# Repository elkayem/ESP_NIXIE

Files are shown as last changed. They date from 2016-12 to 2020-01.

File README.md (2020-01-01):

# ESP_NIXIE

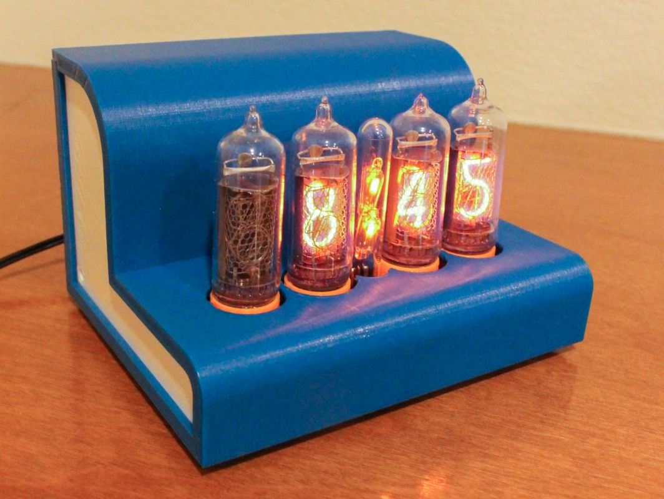
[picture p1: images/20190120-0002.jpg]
Clock 

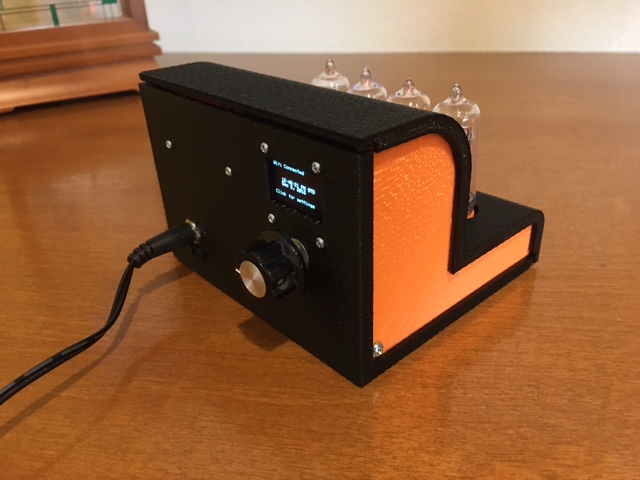
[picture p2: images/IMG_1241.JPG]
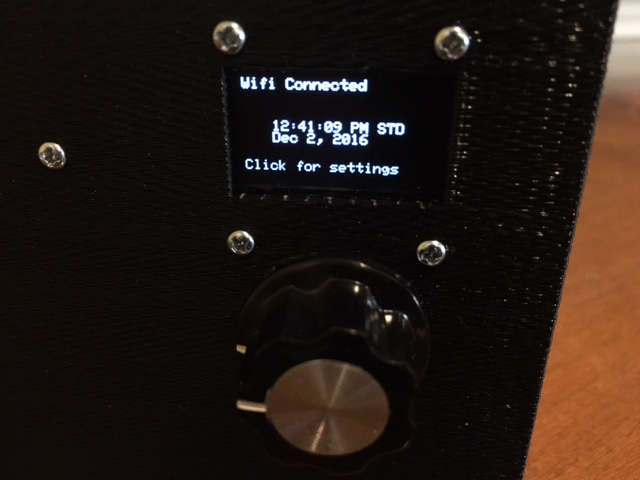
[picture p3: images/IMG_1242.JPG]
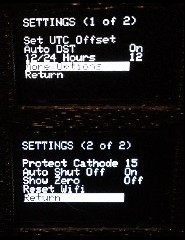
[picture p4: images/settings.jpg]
  

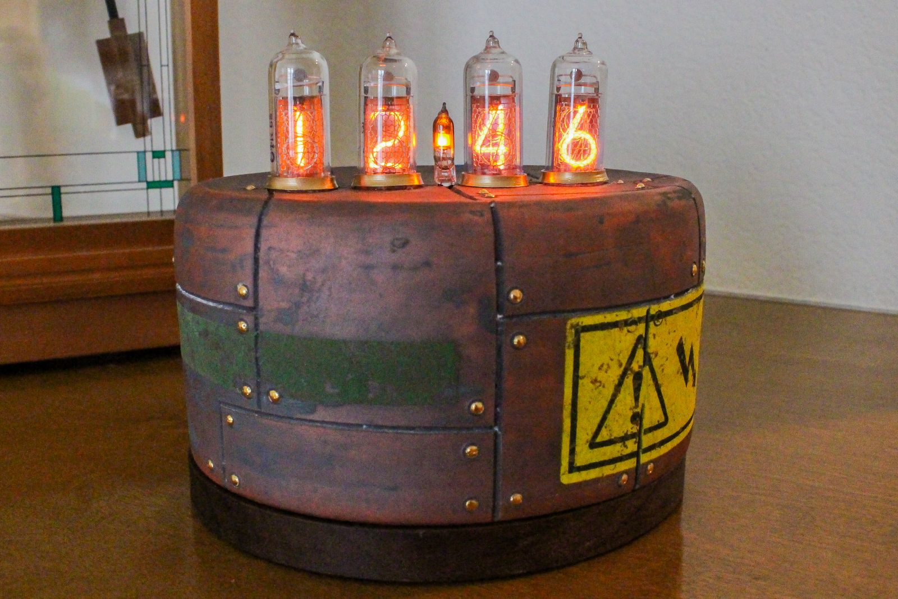
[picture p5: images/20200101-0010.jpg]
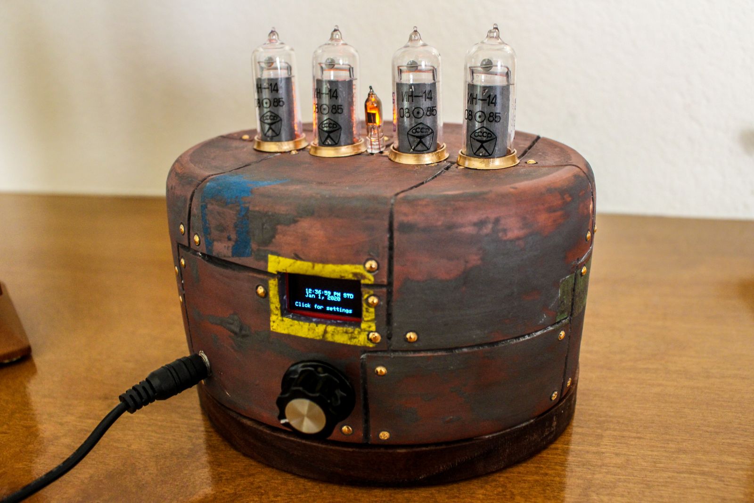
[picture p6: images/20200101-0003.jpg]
  

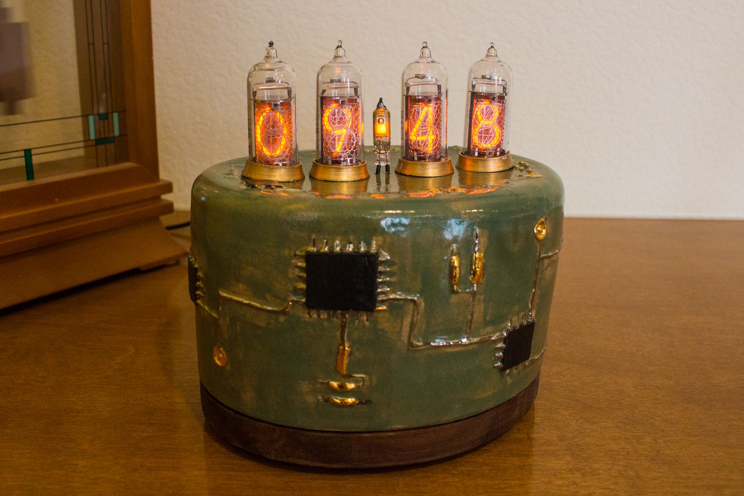
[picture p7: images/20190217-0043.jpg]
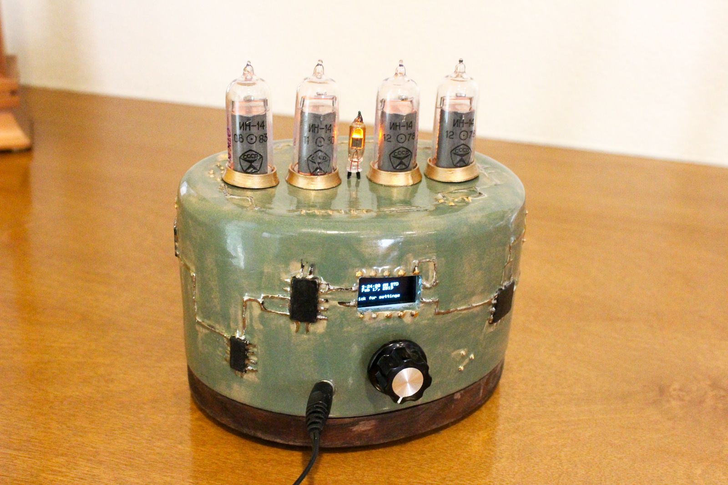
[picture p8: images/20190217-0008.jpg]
  

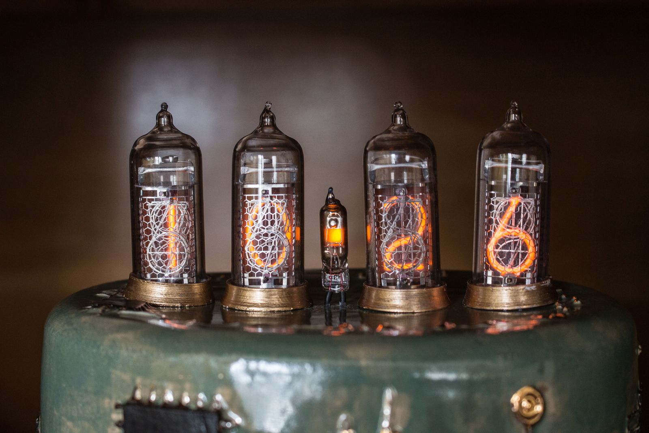
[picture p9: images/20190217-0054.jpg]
 

Building a Nixie Clock is a time honored tradition among makers, and this is yet another DIY Nixie Clock project.  This one is unique in a few respects: 1) it uses an ESP8266 development board as the microcontroller, allowing it to automatically sync its time to NIST over WiFi, and 2) it features a 3D printed frame and hand-solderable PCB. 

These electronics have also been incorporated into a ceramic case by the talented artist [Jackson Fyfe](https://www.jacksonfyfeceramics.com/).  The case you see pictured above is one he created for me.  Head over to his website to see a number of his other stunning Nixie case designs, which he is selling as a limited release.

This repository contains the code, and schematics for driving a Nixie tube clock with a NodeMCU 1.0 ESP8266 development board.  STL files are also provided for a 3D printed case.  Two variants of the PCB and 3D printed cases are available, a PCB and case without a colon separator circuit, and a PCB and case with a colon separator circuit.  The code is the same, with a single #define statement that can be commented to compile the option without the separator circuit.   

When the clock is turned on for the first time, it will create a WiFi access point at ESPNIXIE that can be connected to using a computer or smartphone.  The user can use this access point to specify the WiFi network SSID and password.  This information is stored in EEPROM, so will not be needed the next time the clock is turned on.  It uses the Arduino [Wifi Manager](https://github.com/tzapu/WiFiManager) to create the access point.  

This clock includes a menu-driven OLED screen and rotary encoder, with menu options described below.  All settings are stored in EEPROM so they can be used after a power cycle.
* *Set UTC Offset.*  The user's local time zone is selected by adjusting the time offset from UTC time.
* *Auto DST.* This option enables/disables automatic daylight savings time.  The code includes rules for US Daylight Savings Time (second Sunday in March at 2am to first Sunday in November at 2am).  The code can easily be modified for rules in other countries.
* *12/24 Hours.* This option selects between 12 and 24 hour time formats.
* *Blink Colon.* This option is available if using a colon separator.  If enabled, it will blink the colon once per second, otherwise it will keep the colon on steady.  This option is not available if #define CLOCK_COLON is commented in the code.  
* *Protect Cathode.* Nixie tubes are susceptible to cathode poisoning when material from an active cathode sputters on the inactive cathodes.  This process can be reversed by occasionally cycling through all numbers for short durations.  When enabled, this feature will cycle through all the numbers at a 10 Hz rate for 5 seconds.  Besides protecting the cathodes, it also looks cool.  Time intervals ranging from 15 minutes to two hours can be selected.
* *Auto Shutoff.* When enabled, this feature will automatically turn off the tubes between designated hours (e.g., during the night), helping to preserve Nixie tube life.  The off and on times are selectable through a submenu.
* *Screensaver.* When enabled, a screensaver will activate on the OLED if the menu has been inactive for more than 60 seconds.  OLEDs are subject to screen burn-in, and this will help alleviate that issue.  Two screensaver options are available.  The first displays a scrolling image, and the second simply turns the OLED display off.
* *Show Zero.* This option allows the user to select whether the left most Nixie tube (tens place for the hour) should be turned off when it is zero, or whether zero should be shown.  
* *Reset Wifi.*  Selecting this will cause the ESP8266 to forget the current WiFi network.  The clock will reboot and set up a new WiFi access point at ESPNIXIE.   

In addition to these settings, holding the rotary encoder button down for more than three seconds will manually toggle the Nixie tubes on and off.  If the Auto Shutoff feature is enabled, the Nixies will stay on or off as selected until the next Auto Shutoff transition occurs, after which the Nixie tubes will turn on and off according to the Auto Shutoff schedule.

**Please PM me if you would like a set of printed circuit boards.** I have enough extras to make a few more ESP Nixie clocks.  

## Parts
* NodeMCU V1.0 (Amica board).  Clone boards often are unofficially labeled as V2
* 4 IN-14 Nixie Tubes
* 1 0.96" I2C 128x64 OLED display
* 1 Rotary Encoder
* 1 12VDC 1A Wall Adapter Power Supply
* 1 NCH6100HV High Voltage DC Power Supply (or equivalent)
* 1 Nixie Board PCB (options with or without colon separator circuit).  I've included the Eagle schematic, board layout, and gerber files in this repository for both options.  
* 2 15-pin female headers
* Lots of male breakaway headers (I haven't counted, buy a pack)
* 6 16-pin DIP IC Sockets
* 4 Nixie Tube PCBs.  Files included in this repository.  This can also easily be created using a strip board.
* 2 74HC595N shift registers
* 4 74141N BCD to Decimal Decoders (or K155ID1 Russian equivalents)
* 1 L7805 5V regulator (an additional heat sink is recommended)
* 1 0.33 uF capacitor
* 1 0.1 uF capacitor
* 1 3 Pin 5.08mm Pitch PCB Mount Screw Terminal  
* 1 2 Pin 5.08mm Pitch PCB Mount Screw Terminal 
* 4 15K Ohm resistors
* 1 20K Ohm resistor (used to illuminate decimal point if not using colon separator circuit.  However, I no longer recommend using this resistor for ascetic reasons.)
* Various M2 and M3 bolts
* 8 female-female short jumper cables.
* 1 MPSA42 Transistor (if using colon separator PCB)
* 2 200K Ohm resistors (if using colon separator circuit)
* 1 33K Ohm resistor (if using colon separator circuit)
* 1 IN-3 tube or 2 NE-2H tubes (if using colon separator circuit)

## Instructions
Most of these parts can be found on eBay or your favorite online Chinese retailer.  Although no longer manufactured, nixie tubes are still readily available, with the IN-14 selling for about $5-$10 per tube.  I recommend the NCH6100HV power supply, though there are many others out there capable of driving Nixie tubes.  The output voltage should be set to 170 V, which can be adjusted using an onboard potentiometer.  If selecting a different power supply, make sure it is capable of delivering at least 15 mA of continuous current at 170 V.

The Nixie Board PCB and tube PCBs must be manufactured by a PCB supplier.  The least expensive way to do this is to upload the gerber files (included as a .zip file) to one of several Chinese manufacturers such as JLCPCB, SchenZhen2U, or Seeed Studio.  pcbshopper.com allows a comparison between vendors.  Typical prices are $1-$3/board, with a minimum of 5 boards.  Recommended default settings are Layers: 2; PCB Thickness: 1.6mm; Surface Finish: HASL; Copper Weight: 1.  The main board is 100 x 80 mm, and the smaller tube boards are 20.7mm x 28.3mm.  

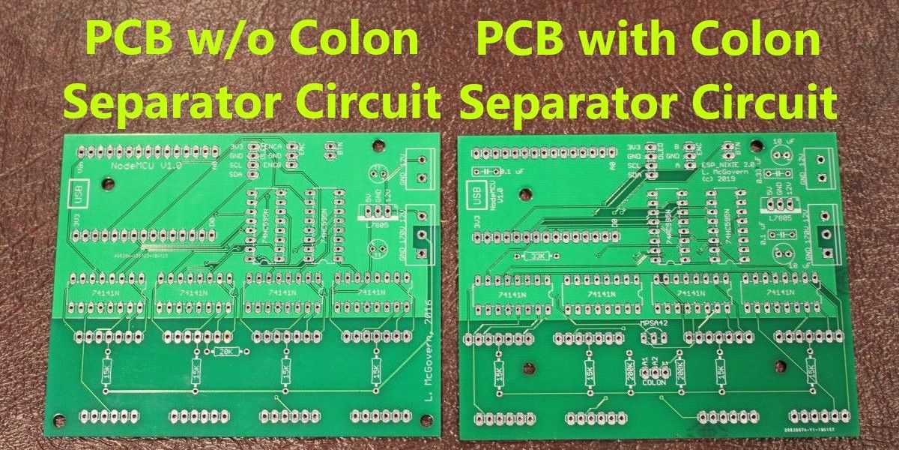
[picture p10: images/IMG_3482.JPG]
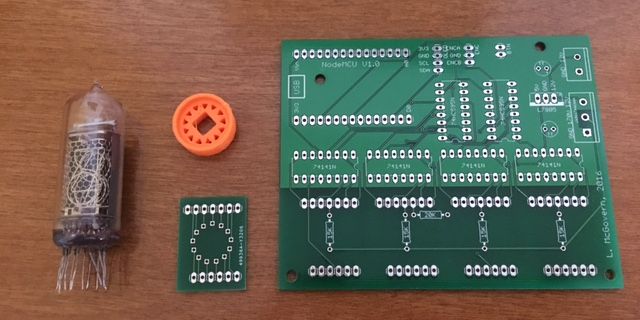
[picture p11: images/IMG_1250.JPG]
 

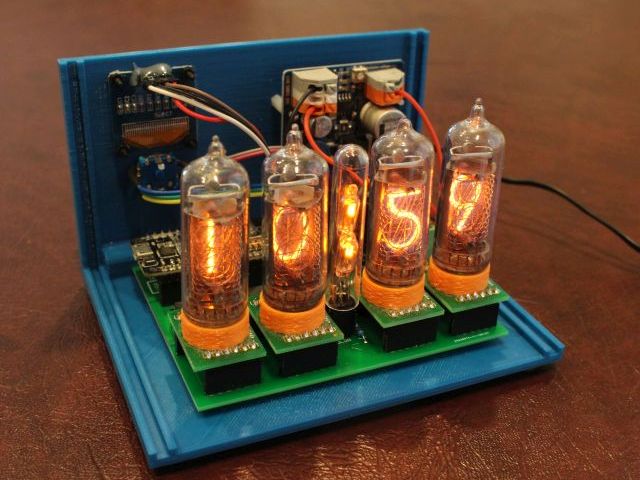
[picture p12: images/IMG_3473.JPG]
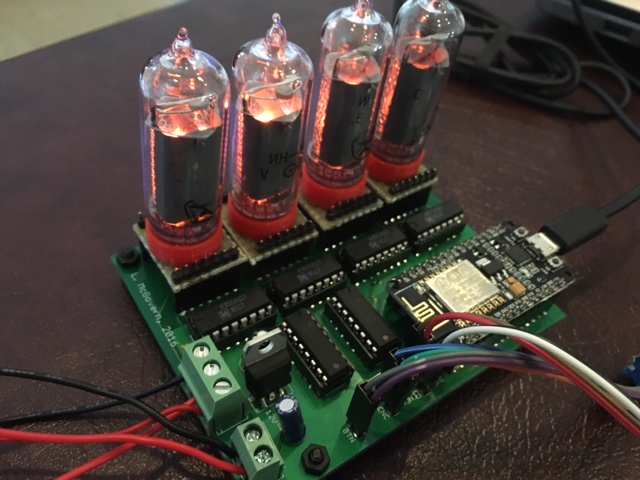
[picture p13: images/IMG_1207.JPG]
 

Solder headers, IC sockets, terminal blocks, resistors, voltage regulator, and capacitors to the board.  The 0.33 uF capacitor goes closest to the 2-pin terminal block.  The 20K Ohm resistor is marked as optional.  This will illuminate the decimal point between the hours and minutes.  Personally, I think it looks better without it and I did not use it, but it is there if others wish to use it.  Mount ICs, and NodeMCU to the headers and sockets.  

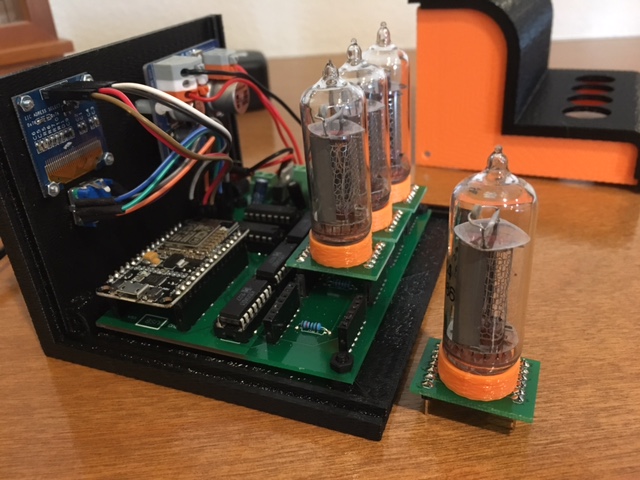
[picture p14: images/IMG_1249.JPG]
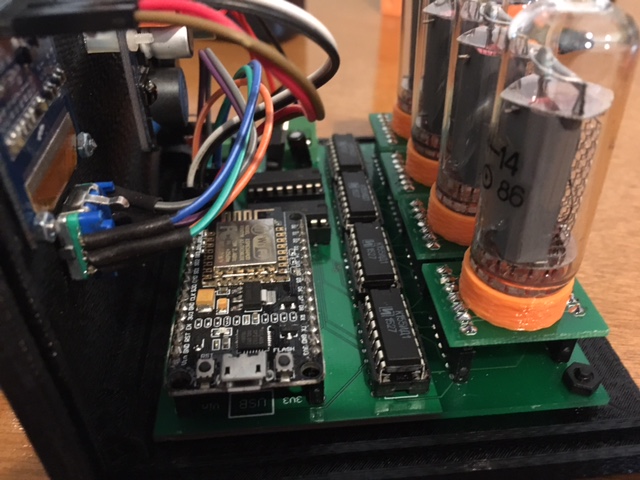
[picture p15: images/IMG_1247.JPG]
 

### Board Modifications
A few recommended modifications to the board are listed below. These changes will be incorporated into a future release of the board design. See figure below for suggested modifications to back of board.

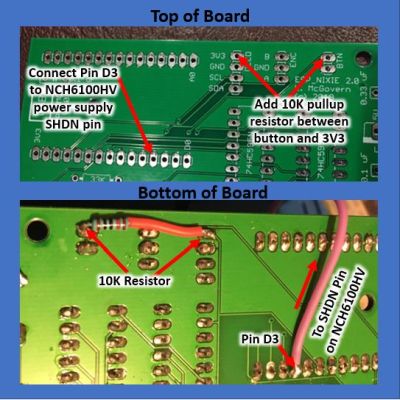
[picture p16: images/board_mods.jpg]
 

**Button Pullup Resistor.** The encoder button is attached to pin D0 (GPIO16). This button requires a 10K pullup resistor to keep D0 high when the button is not depressed.  Unfortunately, the ESP-12E module on the NodeMCU board does not have a pullup resistor on this pin. It does have an LED which can sometimes function as a pullup resistor, so it is possible that your NodeMCU board will work just fine without this modification. NodeMCU boards with a blue LED on pin D0 require the additional 10K pullup resistor, while boards with a red LED can often function without one. See above figure for suggested configuration, with the non-grounded side of the button pin connected to 3.3V via a 10K resistor. The resistor can be soldered to the back of the board.

**Power Supply Shutdown Pin (Optional).** The auto shutoff feature will turn off the Nixie tubes at night to preserve Nixie tube life. This is primarily done by controlling the 74141N transistors. This still leaves the Nixie anodes connected to the 170V power supply, which can show a slight orange glow on the tubes visible in the dark. If using the NCH6100HV power supply, the 170V output can be completely turned off using the SHDN pin on the power supply, thereby completely eliminating the orange glow. To take advantage of this feature, solder a wire on the back side of the ESP_NIXIE board to the D3 pin, and connect the other end of the wire to the SHDN pin on the NCH6100HV. See purple wire on the above photo for pin location on the board. 

### Final Assembly
3D print the parts.  The top cover is printed on its side, and will need supports to prevent the tube holes from sagging.  Four tube sockets are required.  

Mount Nixie tubes through 3D printed tube sockets, and then through the tube PCBs.  Be careful to make sure the anode wire (the rear wire on the tube with an arrow pointing to it) goes through the PCB hole that connects to the center pin of the 7-pin header.  I should have marked it on the PCB.  Also, the side of the PCB with the traces is the top side.  It will not plug into the board if the tube is soldered to the wrong side.  

Mount the board to the 3D printed base with M3 bolts, and the OLED and HV power supply with M2 bolts.  Mount the rotary encoder to the back of the case.  Wire the 2-pin terminal block to the 12V wall power supply, and the 3-pin terminal block to the HV power supply using loose wire.  The GND can go to either side of the HV power supply, but make sure the terminal labeled 12V goes to Vin, and terminal labeled 170V goes to HV.  Connect the OLED to the four OLED pins on the board using jumper cables.  The rotary encoder should have three pins on one side and two on the other.  Connect the three pins to the 3 ENC headers on the board, and the two pins to the 2 BTN pins on the board.  If the jumper cables on the encoder are loose, you may wish to solder them on directly.  I did.

Flash software to ESP8266 using a micro-USB cable.  This can be done one of two ways: a) Use the compiled .bin files included in the repository, or b) compile and flash the firmware using the Arduino IDE.  For upload, I recommend using esptool at https://github.com/espressif/esptool to flash the esp8266.  After installing esptool (`pip install esptool`, or `python -m pip install esptool`), the following line is used to flash the ESP8266:

`esptool.py --port COM6 write_flash 0x0000 ESP_NIXIE_with_colon_separator.bin`
  
where COM6 should be replaced by whatever com port your device is plugged into. (In Windows, this is discoverable using the Device Monitor.) **Important:** I recommend unplugging the NodeMCU from the ESP_NIXIE board before flashing. This is because the encoder pins are attached to the Serial TX and RX pins, and can interfere with communication during upload.

Glue the case side panels to the top cover.  I use plastic epoxy.  Close the case and attach on the side corners using (optional) 1/2" #4 or #6 sheet metal screws.

When first powering the ESP Nixie clock, it will create a wireless access point called ESPCLOCK with default password: PASSWORD.  Connect to the wireless access point with a computer, and open 192.168.4.1 in a web browser if the configuration page does not automatically open.  This configuration page can be used to set your clock to connect to your home WiFi network.  

## Special Instructions for Compiling and Flashing Firmware Using Arduino IDE
There are a few configurable options in the code which may require recompiling. 

The default access point network name and password are hardcoded in lines, which may be changed as desired:

```
#define AP_NAME "ESPCLOCK"
#define AP_PASSWORD "PASSWORD"
```  

To compile the code without the colon separator PCB, comment out the following line.  This removes the option to enable/disable the circuit from blinking in the menu.

`#define CLOCK_COLON \\ Comment out if not using colon separator PCB`

Also note that if you do not see any text at all on the screen, I2C address of the OLED screen may be incorrect.  The code uses 0x3C, which is fairly common.  The I2C_Scanner can determine if your screen has a different address.  The address in the code can be modified and recompiled as necessary.

The steps to recompile and flash the firmware through the Arduino IDE are listed below.
1. Configure Arduino IDE
   1. Install Arduino IDE 1.8.10 (or later) from arduino.cc
   2. Open File>Preferences, and enter the following URL into "Additional Board Manager URLs": http://arduino.esp8266.com/stable/package_esp8266com_index.json
   3. Open Tools>Board>Board Manager and install the esp8266 boards.  ***Important Step:*** Use the "Select Version" pull down menu to select version **2.5.2**. At the present date (1/1/2020), the latest version (2.6.3) is not reliable with this code and electronics. If you are experiencing issues with the clock failing to reconnect to your wifi network after a power cycle, you may have missed this step and need to revert to 2.5.2.
   4. In the Tools menu, configure Board: NodeMCU 1.0 (ESP-12E Module), CPU Frequency: 80 MHz, Upload Speed: 115200.
2. Install the following libraries.  I have indicated which versions I am currently using (as of 1/1/2020), though in most cases later versions should work: NTPClient (3.2.0), WiFi (1.2.7), WiFiManager (0.15.0-beta), Time (1.6.0), Timezone (1.2.3), Adafruit_GFX (1.7.2), Adafruit_SSD1306 (2.0.3), and Switch (1.2.1).  All of these libraries are added through the Library Manager (Sketch > Include Library > Manage Libraries).   
3. Connect the NodeMCU board to your computer using a micro USB cable, and set Tools>Port to the new port that appears.  Your computer should automatically install the driver, but if it does not, you may need to manually download and install the CP2102 driver from http://www.silabs.com/products/mcu/pages/usbtouartbridgevcpdrivers.aspx.  **Suggestion:** I recommend unplugging the NodeMCU from the ESP_NIXIE board before flashing. This is because the encoder pins are attached to the Serial TX and RX pins, and can interfere with communication during upload. Note these pins should be open if the rotary encoder is in a detent position, so you may still be able to get away with flashing the NodeMCU while it is still attached to the ESP_NIXIE board. Be sure to unplug it from the wall first, though!
4. Press the Upload button to compile the sketch and upload to the NodeMCU.  The most common reason for failing to compile are an selecting the wrong board or not installing all the required libraries.

Hope you find this useful, and please do send me a picture if you make one of these!

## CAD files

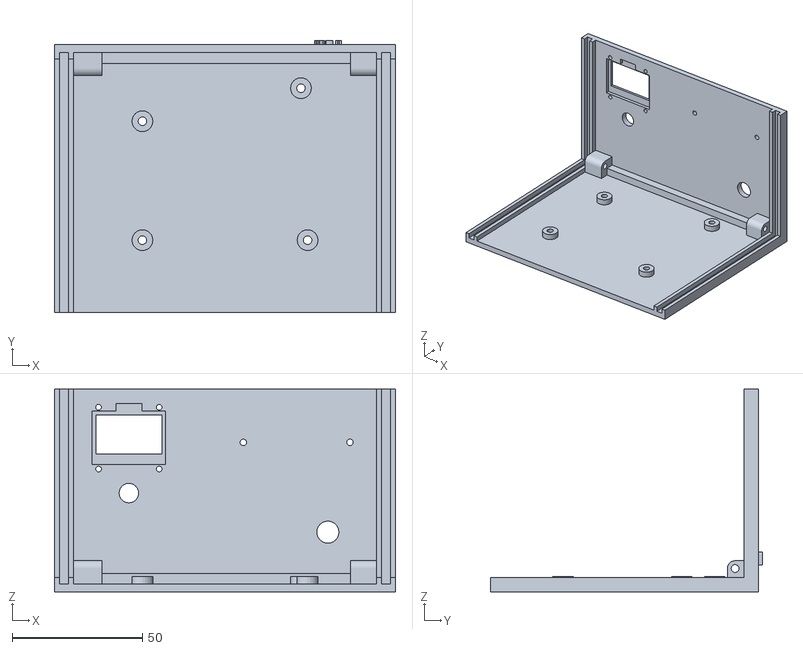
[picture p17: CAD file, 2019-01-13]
3D Printer Files/Case_with_colon/NixieBaseWithColon.stl
131.1 x 104.5 x 78.0

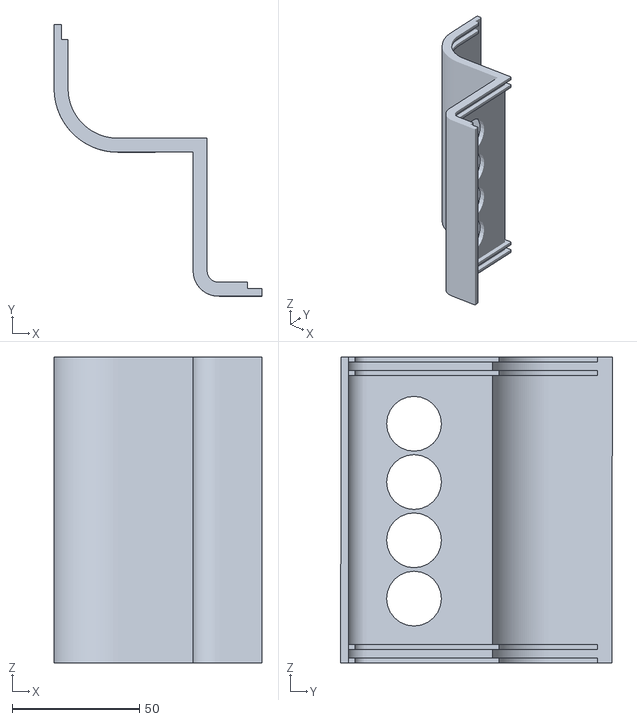
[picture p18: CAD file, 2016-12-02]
3D Printer Files/Case_without_colon/NixieClockCaseCover.stl
81.5 x 106.5 x 120.0

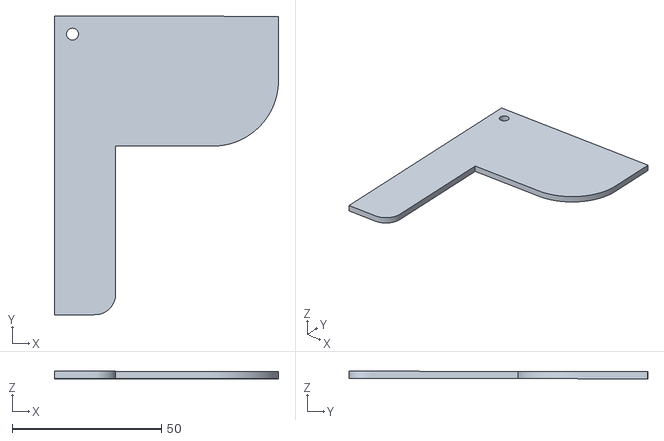
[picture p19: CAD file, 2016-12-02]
3D Printer Files/NixieClockSide.stl
75.0 x 100.0 x 2.52

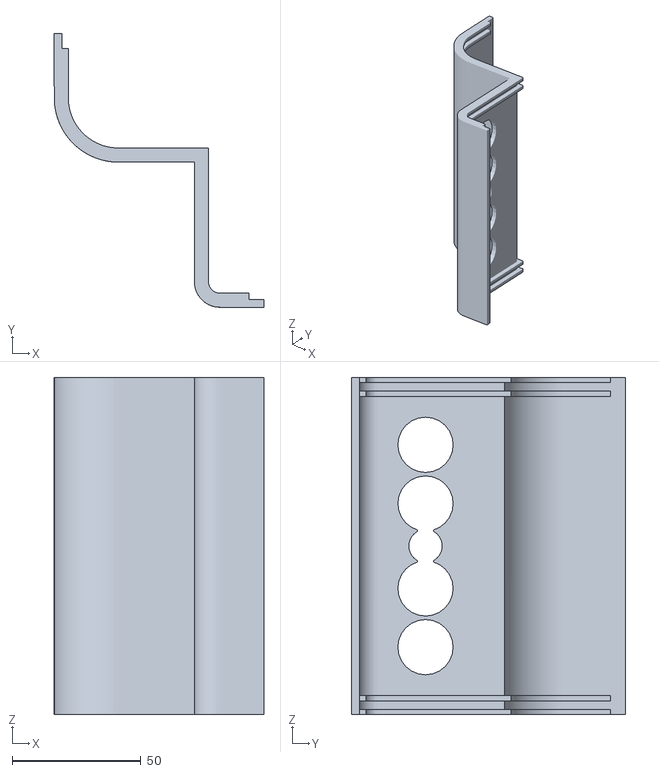
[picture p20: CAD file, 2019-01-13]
3D Printer Files/Case_with_colon/NixieCoverWithColon.stl
81.5 x 106.5 x 131.1

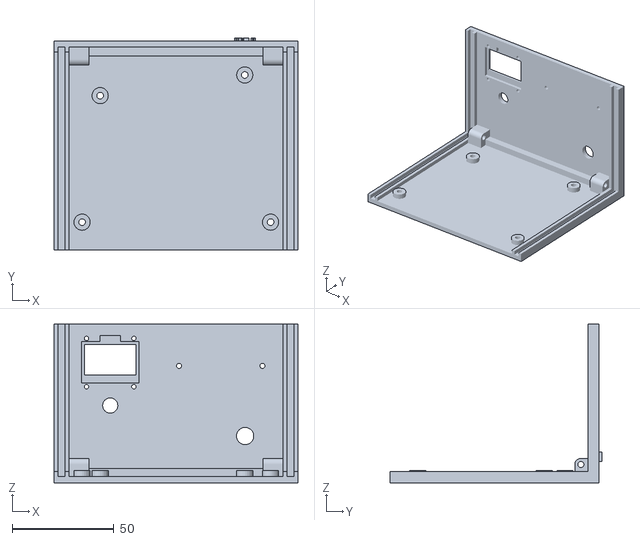
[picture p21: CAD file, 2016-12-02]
3D Printer Files/Case_without_colon/NixieClockCaseBase.stl
120.0 x 104.5 x 78.0

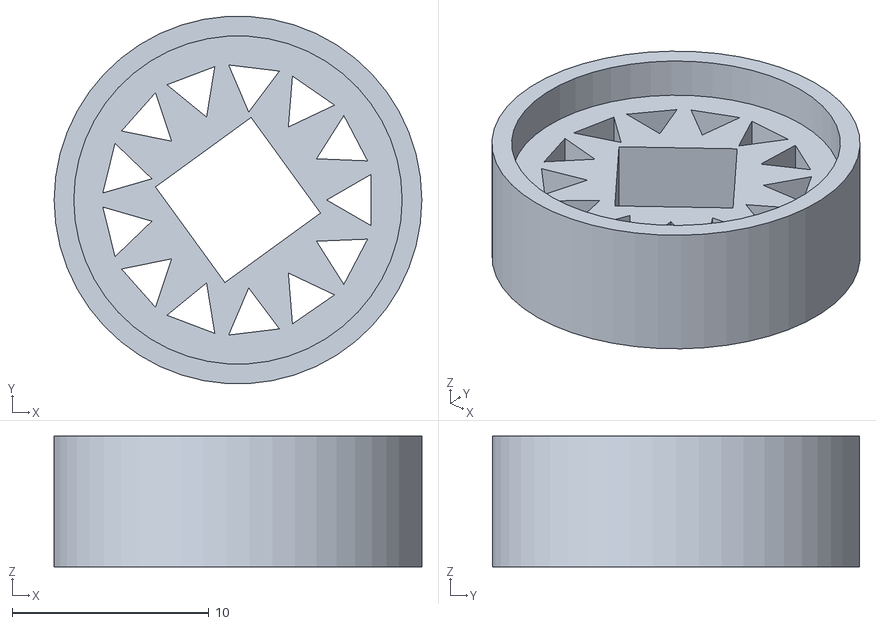
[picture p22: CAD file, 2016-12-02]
3D Printer Files/TubeBase.stl
18.7 x 18.6 x 6.65

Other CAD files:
3D Printer Files/Case_with_colon/NixieClockCaseWithColon.skp
3D Printer Files/Case_without_colon/NixieClockCase.skp

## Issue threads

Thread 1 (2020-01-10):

Clock not working

HonzaPo, 2020-01-10:
Hi,
I would ask for help. I tried to build a clock, but they don't work. Nixie doesn't show anything. Wifi settings work, oled display shows time. I tried the test code `www.instructables.com/id/Driving-two-Nixie-tubes-with-an-Arduino-via-a-shif/` with esp modification and it works, so I don't know what's wrong. Code in Annex. I use: NodeMCU V3.0 (Clone board). Esp8266 boards version 2.5.2.
Thank you.

[ESP test nixie.txt](https://github.com/elkayem/ESP_NIXIE/files/4046478/ESP.test.nixie.txt)

elkayem, 2020-01-10:
Hmm...  the fact that the nixies work with the code from the instructables site suggests that you should be seeing something on the tubes. Double check that your wiring matches my schematic since it does look like the sample code you sent is a little different.  Also, use my latest version of code (from last week) and check that pin D3 with a multimeter. It should be high. If it is low, then the code is turning off the nixies for some reason, likely from the Auto Shutoff feature.

Can you use the rotary encoder to change the settings? Check to see if the Auto Shutoff feature is disabled. If the button on the rotary encoder isn't working reliably, it could be that you need to add a 10K pullup resistor from pin D0 to 3.3V. (I really need to add that to the schematic.) Most boards seem to get by without that resistors, but a few don't. See my github page for more details. I updated it recently.

I have not used this with the NodeMCU V3.0, but I think it is the same except for size. It is possible but unlikely that there is some subtle difference. You may be the first one to try it with that board.

Other than that, it may take a little troubleshooting. I can assure you that many people have built this and have it working, so it probably isn't a bug with the code. If you do find an issue though, please do let me know.

Larry

HonzaPo, 2020-01-12:
Problem solved. I connected oscilloscope to pins D5, D6, D7 no data (square signal), only 3.3v. I changed the cable and uploaded again program and it works. I don't know why everything worked (display, encoder, wifi) except the shift register signal. I use a rotary encoder module, and it has preparation for a pullup resistor. Thanks for the help and great tutorial. How can I send you a photo of clock as you have requested on the github page after I finish them?

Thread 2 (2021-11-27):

20K resistor for w/o colon separator circuit

lstolowski, 2021-11-27:
Hi @elkayem. ESP_NIXIE is a cool project for me, a newbie :).
I'making your project with a non-colon separator circuit PCB board. You wrote on the README: "The 20K Ohm resistor is marked as optional. This will illuminate the decimal point between the hours and minutes". It is not clear to me. Did I understand correctly that when I'm using a non-colon separator circuit PCB, I should add a 20K resistor OR the IN-3 tube instead of this resistor?
What about the `#define CLOCK_COLON` line - should it be commented out IF the resistor is there, but if I use the IN-3 I should leave it?
I'll be grateful for your clarifications. Thanks!

elkayem, 2021-11-27:
It is there if you want the decimal point illuminated. Personally I think it is better to leave it out, even if you don’t have the colon circuit enabled.

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

lstolowski, 2021-11-29:
Hi, thanks for your answer, but I still don't get it. Where the ilumination lamp (IN-3) should be mounted if I have got a non-colon PCB? I'd like to have a colon illumination...

Closed 2021-12-03.

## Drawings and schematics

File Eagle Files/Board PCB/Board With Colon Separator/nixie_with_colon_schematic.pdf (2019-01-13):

74HC595N | +3V³
GND | +3V³ | GND | +5V

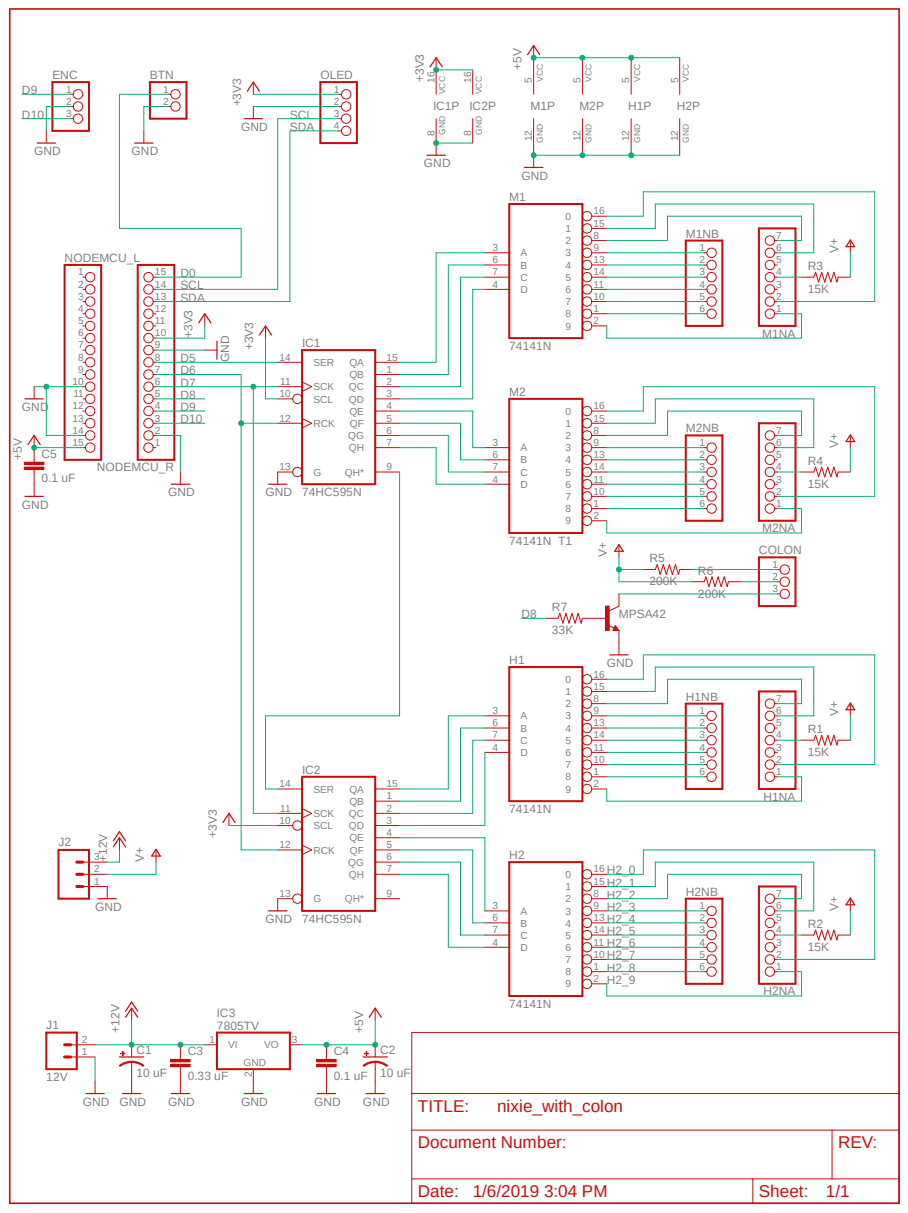
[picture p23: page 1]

Document Number: | REV:

Date: 1/6/2019 3:04 PM | Sheet: 1/1

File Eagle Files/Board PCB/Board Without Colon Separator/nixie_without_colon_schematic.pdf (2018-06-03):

74HC595N | +³V3
GND | +³V3 | GND | +⁵V

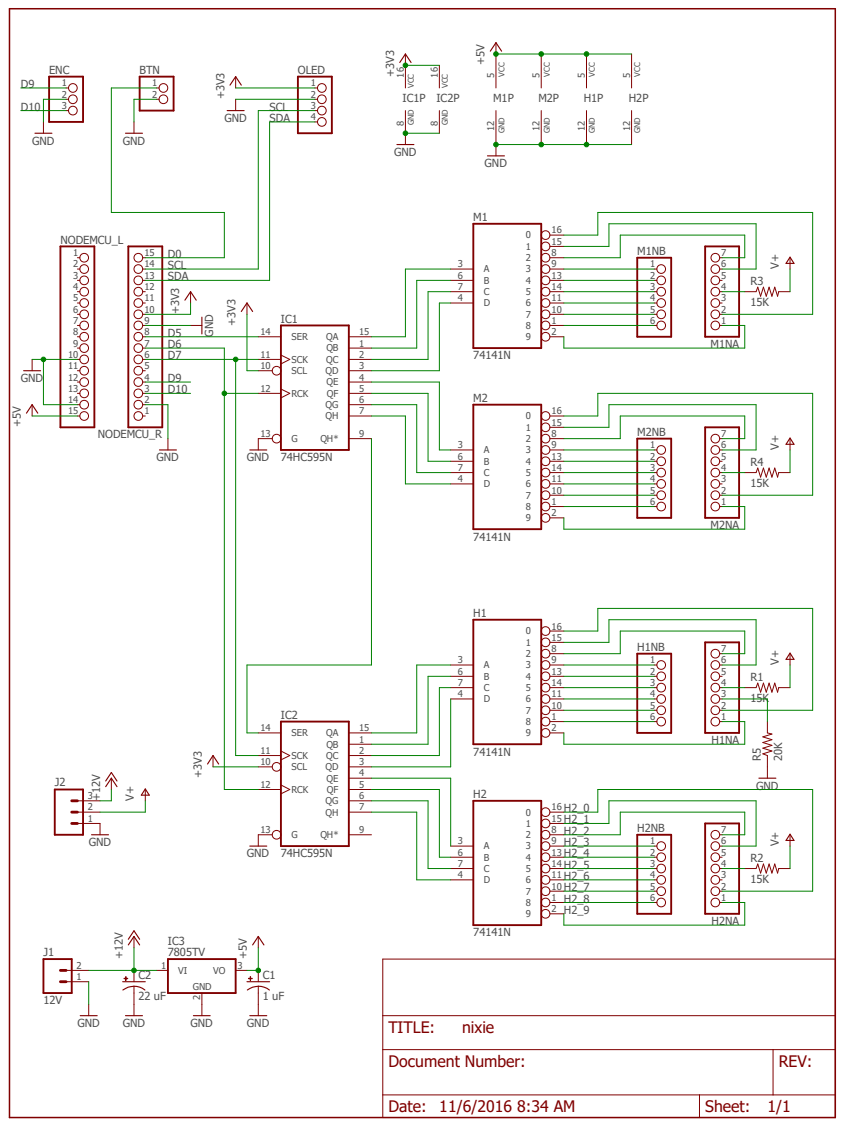
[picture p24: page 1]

Document Number: | REV:

Date: 11/6/2016 8:34 AM | Sheet: 1/1

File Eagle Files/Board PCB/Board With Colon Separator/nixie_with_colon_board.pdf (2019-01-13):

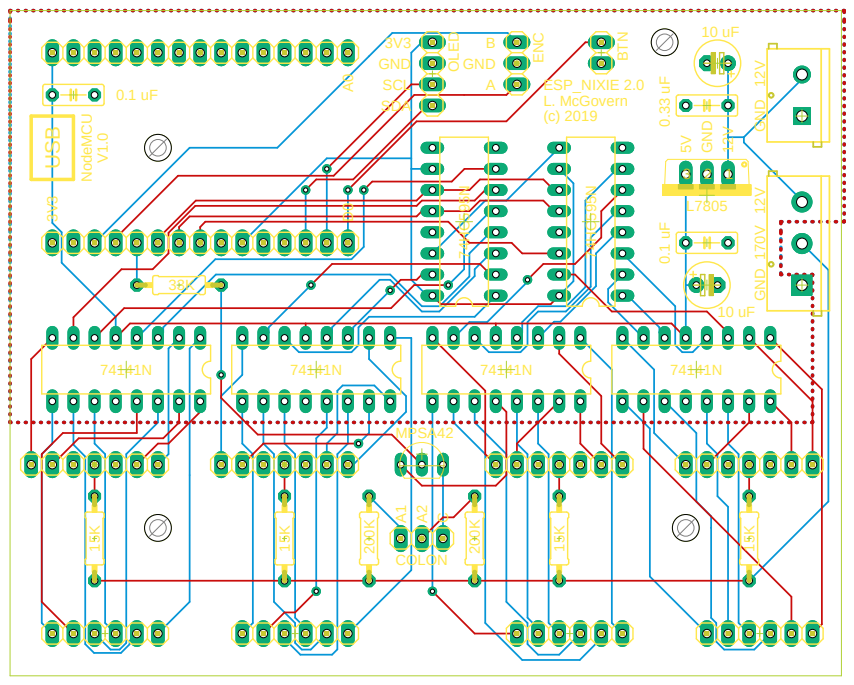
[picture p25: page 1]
OLED ENC BTN3V3 GND SCL SDA; GND; A 12V 12V GND GND ¹⁷⁰V; 74141N ⁷⁴HC⁵⁹⁵N; 74HC⁵⁹⁵N; L7805 ⁵VGND 12V 15K; 15K NodeMCU USB; ESP_NIXIE 2.0; L. McGovern; MPSA42; COLON

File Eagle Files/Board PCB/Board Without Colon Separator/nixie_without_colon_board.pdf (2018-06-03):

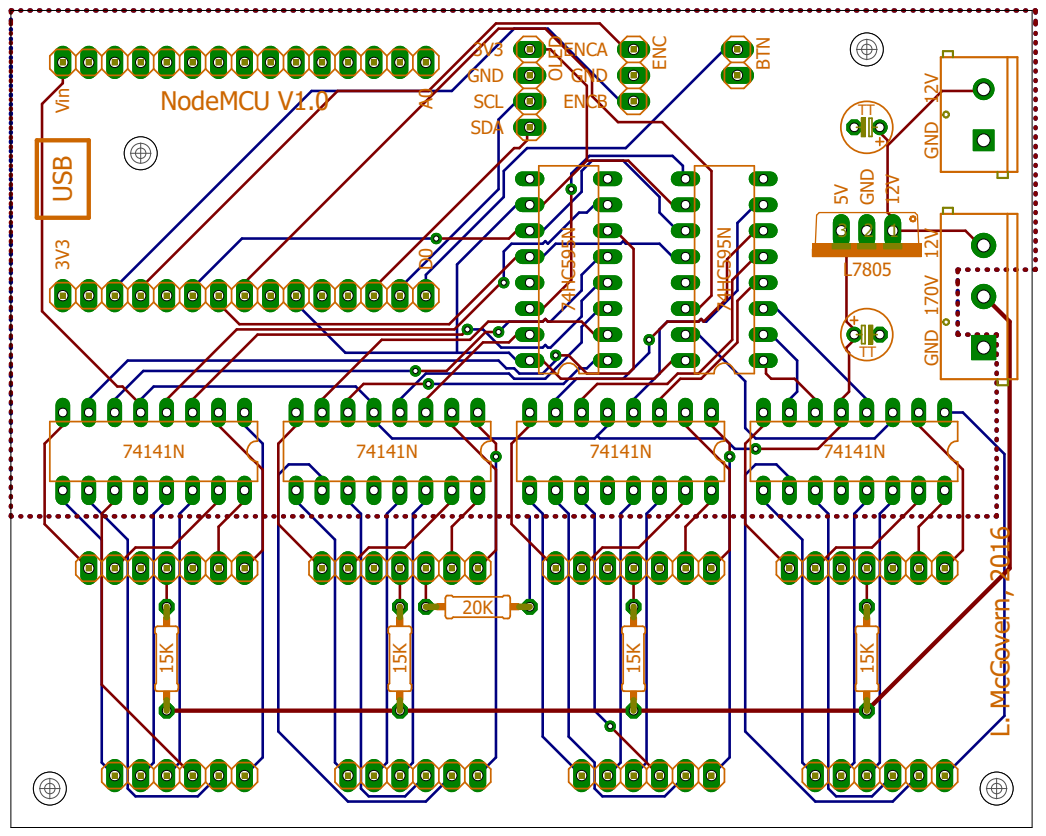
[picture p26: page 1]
SCL SDA; GND; ENCA; ENCB; 12V 12V GND GND ¹⁷⁰V; 74141N ⁷⁴HC595N; L7805 ⁵VGND 12V 15K; NodeMCU V1.0 USB 3V3 Vin

L. McGovern, 2016 OLED ENC BTN3V3 GND

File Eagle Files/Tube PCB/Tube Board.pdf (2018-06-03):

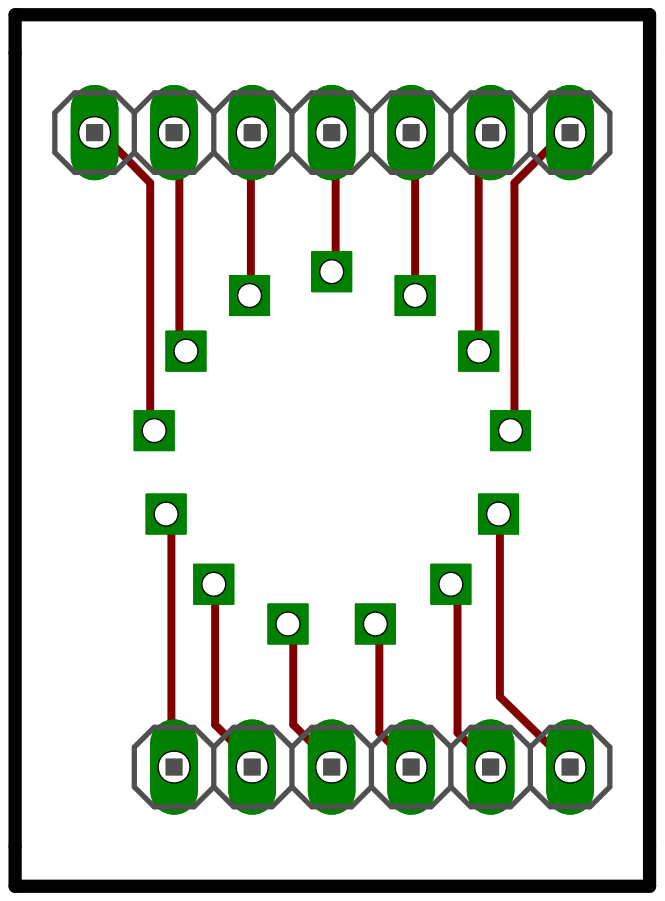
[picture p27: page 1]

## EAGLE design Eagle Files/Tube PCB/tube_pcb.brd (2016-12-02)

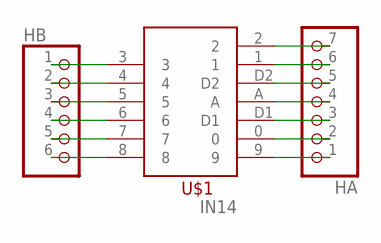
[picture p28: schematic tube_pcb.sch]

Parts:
HA: PINHD-1X7; 1X07
HB: PINHD-1X6; 1X06
U$1: IN14

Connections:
0: HA.2, U$1.0
1: HA.6, U$1.1
2: HA.7, U$1.2
3: HB.1, U$1.3
4: HB.2, U$1.4
5: HB.3, U$1.5
6: HB.4, U$1.6
7: HB.5, U$1.7
8: HB.6, U$1.8
9: HA.1, U$1.9
A: HA.4, U$1.A
D1: HA.3, U$1.D1
D2: HA.5, U$1.D2

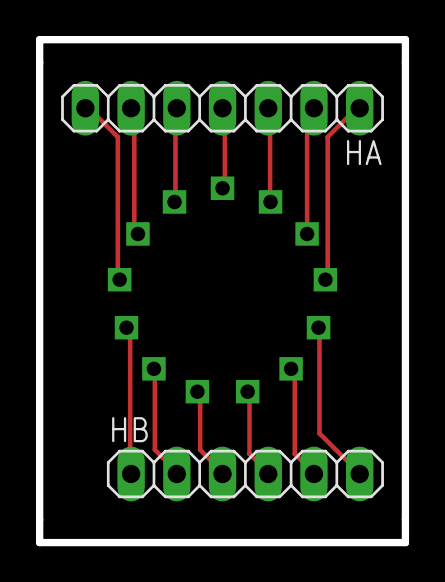
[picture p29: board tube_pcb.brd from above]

Board: 2 copper layers, 20.3 x 27.9 mm, 3 parts (0 on the bottom side), 13 nets.

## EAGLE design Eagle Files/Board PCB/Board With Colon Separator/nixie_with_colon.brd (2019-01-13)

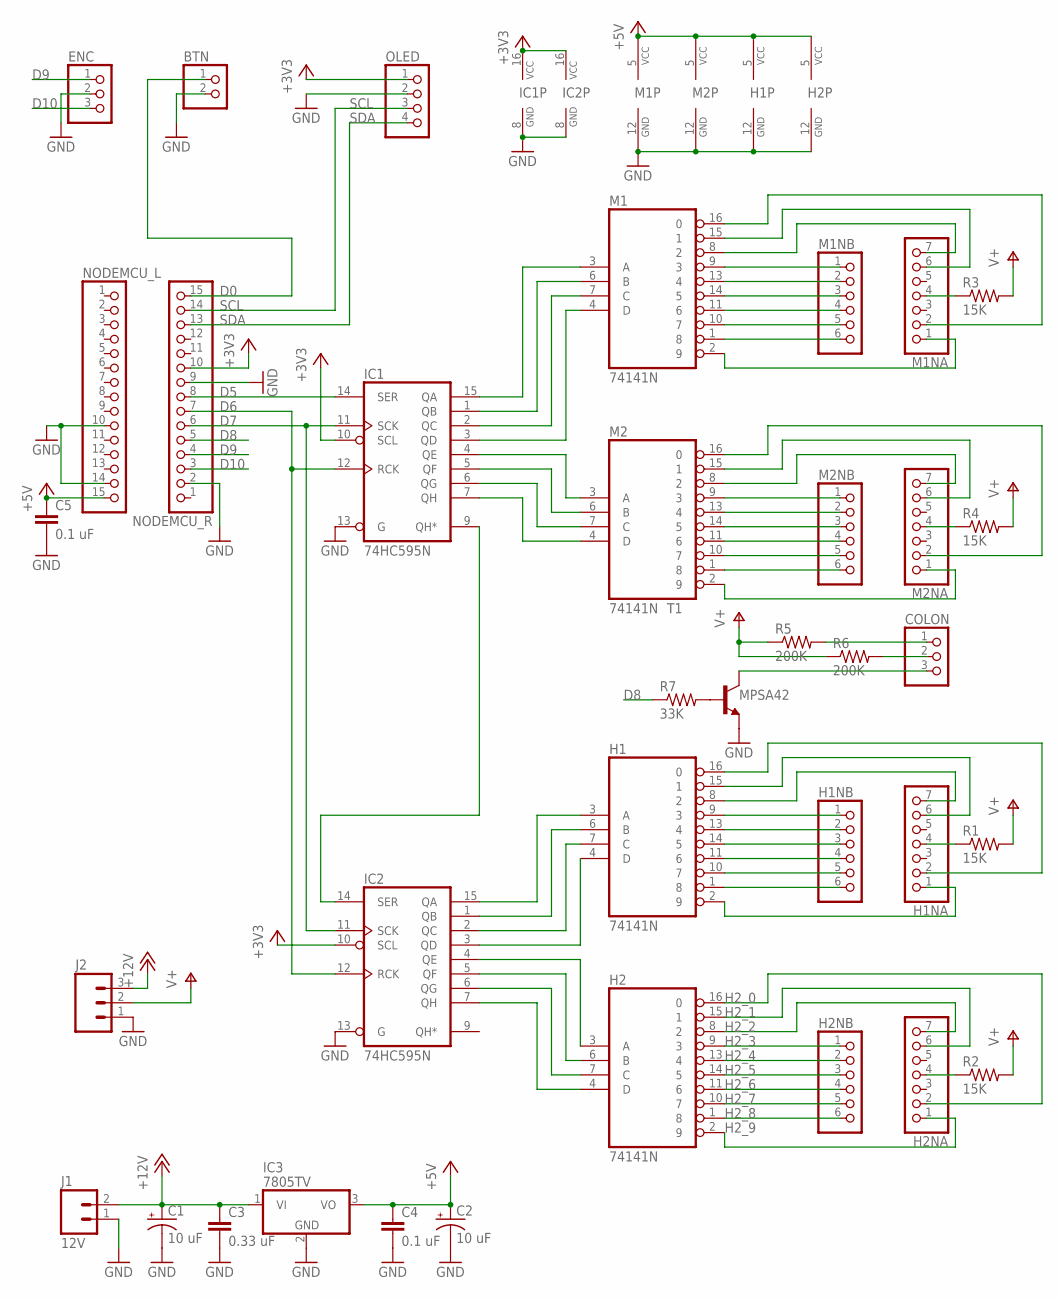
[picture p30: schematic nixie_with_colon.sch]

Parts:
BTN: PINHD-1X2; 1X02
C1, C2: 10 uF; E2,5-6
C3: 0.33 uF; C050-025X075
C4, C5: 0.1 uF; C050-025X075
COLON: PINHD-1X3; 1X03
ENC: PINHD-1X3; 1X03
H1, H2: 74141N; DIL16
H1NA, H2NA: PINHD-1X7; 1X07
H1NB, H2NB: PINHD-1X6; 1X06
IC1, IC2: 74HC595N; DIL16
IC3: 7805TV; TO220V
J1: 12V; SCREWTERMINAL-5MM-2
J2: M03-SCREW-5MM; SCREWTERMINAL-5MM-3
M1, M2: 74141N; DIL16
M1NA, M2NA: PINHD-1X7; 1X07
M1NB, M2NB: PINHD-1X6; 1X06
NODEMCU_L: PINHD-1X15; 1X15
NODEMCU_R: PINHD-1X15; 1X15
OLED: PINHD-1X4; 1X04
R1, R2, R3, R4: 15K; 0207/10
R5, R6: 200K; 0207/10
R7: 33K; 0207/10
T1: MPSA42; TO92-EBC

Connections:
+3V3: IC1.10 (SCL), IC1.16 (VCC), IC2.10 (SCL), IC2.16 (VCC), NODEMCU_R.10, OLED.1
+5V: C2.+, C4.1, C5.1, H1.5 (VCC), H2.5 (VCC), IC3.3 (VO), M1.5 (VCC), M2.5 (VCC), NODEMCU_L.15
+12V: C1.+, C3.1, IC3.1 (VI), J1.2, J2.3
D0: BTN.1, NODEMCU_R.15
D5: IC1.14 (SER), NODEMCU_R.8
D6: IC1.12 (RCK), IC2.12 (RCK), NODEMCU_R.7
D7: IC1.11 (SCK), IC2.11 (SCK), NODEMCU_R.6
D8: NODEMCU_R.5, R7.1
D9: ENC.1, NODEMCU_R.4
D10: ENC.3, NODEMCU_R.3
GND: BTN.2, C1.-, C2.-, C3.2, C4.2, C5.2, ENC.2, H1.12 (GND), H2.12 (GND), IC1.8 (GND), IC1.13 (G), IC2.8 (GND), IC2.13 (G), IC3.2 (GND), J1.1, J2.1, M1.12 (GND), M2.12 (GND), NODEMCU_L.10, NODEMCU_L.14, NODEMCU_R.2, NODEMCU_R.9, OLED.2, T1.E
H2_0: H2.16 (0), H2NA.2
H2_1: H2.15 (1), H2NA.6
H2_2: H2.8 (2), H2NA.7
H2_3: H2.9 (3), H2NB.1
H2_4: H2.13 (4), H2NB.2
H2_5: H2.14 (5), H2NB.3
H2_6: H2.11 (6), H2NB.4
H2_7: H2.10 (7), H2NB.5
H2_8: H2.1 (8), H2NB.6
H2_9: H2.2 (9), H2NA.1
unnamed: H1.16 (0), H1NA.2
unnamed: H1.2 (9), H1NA.1
unnamed: H1.9 (3), H1NB.1
unnamed: H1.13 (4), H1NB.2
unnamed: H1.14 (5), H1NB.3
unnamed: H1.11 (6), H1NB.4
unnamed: H1.10 (7), H1NB.5
unnamed: H1.1 (8), H1NB.6
unnamed: H1.8 (2), H1NA.7
unnamed: H1.15 (1), H1NA.6
unnamed: H1NA.4, R1.1
unnamed: COLON.2, R6.2
unnamed: COLON.1, R5.2
unnamed: COLON.3, T1.C
unnamed: R7.2, T1.B
unnamed: H2NA.4, R2.1
unnamed: M1.16 (0), M1NA.2
unnamed: M1.9 (3), M1NB.1
unnamed: M1.13 (4), M1NB.2
unnamed: M1.14 (5), M1NB.3
unnamed: M1.11 (6), M1NB.4
unnamed: M1.10 (7), M1NB.5
unnamed: M1.1 (8), M1NB.6
unnamed: M1.2 (9), M1NA.1
unnamed: M1.8 (2), M1NA.7
unnamed: M1.15 (1), M1NA.6
unnamed: M1NA.4, R3.1
unnamed: M2.16 (0), M2NA.2
unnamed: M2.9 (3), M2NB.1
unnamed: M2.13 (4), M2NB.2
unnamed: M2.14 (5), M2NB.3
unnamed: M2.11 (6), M2NB.4
unnamed: M2.10 (7), M2NB.5
unnamed: M2.1 (8), M2NB.6
unnamed: M2.2 (9), M2NA.1
unnamed: M2.8 (2), M2NA.7
unnamed: M2.15 (1), M2NA.6
unnamed: M2NA.4, R4.1
unnamed: IC1.15 (QA), M1.3 (A)
unnamed: IC1.1 (QB), M1.6 (B)
unnamed: IC1.2 (QC), M1.7 (C)
unnamed: IC1.3 (QD), M1.4 (D)
unnamed: IC1.4 (QE), M2.3 (A)
unnamed: IC1.5 (QF), M2.6 (B)
unnamed: IC1.6 (QG), M2.7 (C)
unnamed: IC1.7 (QH), M2.4 (D)
unnamed: H1.3 (A), IC2.15 (QA)
unnamed: H1.6 (B), IC2.1 (QB)
unnamed: H1.7 (C), IC2.2 (QC)
unnamed: H1.4 (D), IC2.3 (QD)
unnamed: H2.3 (A), IC2.4 (QE)
unnamed: H2.6 (B), IC2.5 (QF)
unnamed: H2.7 (C), IC2.6 (QG)
unnamed: H2.4 (D), IC2.7 (QH)
unnamed: IC1.9 (QH*), IC2.14 (SER)
SCL: NODEMCU_R.14, OLED.3
SDA: NODEMCU_R.13, OLED.4
V+: J2.2, R1.2, R2.2, R3.2, R4.2, R5.1, R6.1

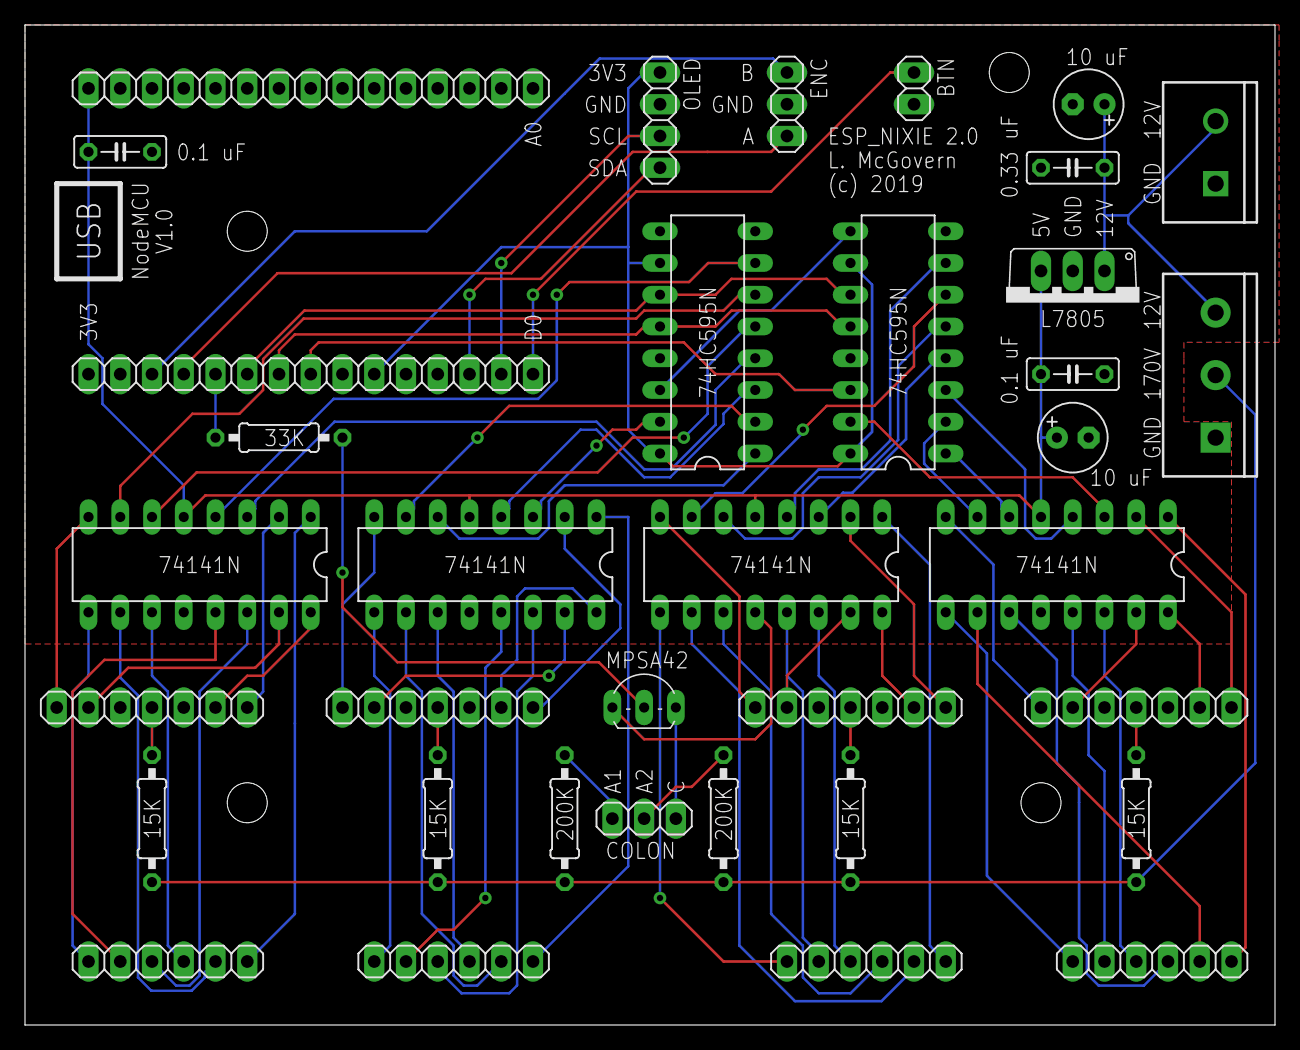
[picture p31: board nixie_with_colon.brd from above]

Board: 2 copper layers, 100.0 x 80.0 mm, 36 parts (0 on the bottom side), 79 nets.

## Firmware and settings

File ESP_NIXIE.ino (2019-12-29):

/* 
 *    ESP Nixie Clock 
 *	  Copyright (C) 2019  Larry McGovern
 *	
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
 *    This program is distributed in the hope that it will be useful,
 *    but WITHOUT ANY WARRANTY; without even the implied warranty of
 *    MERCHANTABILITY or FITNESS FOR A PARTICULAR PURPOSE.  See the
 *    GNU General Public License <http://www.gnu.org/licenses/> for more details.
 */
	
#include <ESP8266WiFi.h>
#include <NTPClient.h>
#include <WiFiUdp.h>
#include <TimeLib.h>
#include <Timezone.h>
#include <Wire.h>
#include <WiFiManager.h>
#include <EEPROM.h>
#include <Adafruit_GFX.h>
#include <Adafruit_SSD1306.h>
#include <avdweb_Switch.h>
#include <Ticker.h>

#define AP_NAME "ESPCLOCK"
#define AP_PASSWORD "PASSWORD"

#define CLOCK_COLON //  Comment out if not using colon separator PCB

#define D0 16 // LED_BUILTIN
#define D1 5 // I2C Bus SCL (clock)
#define D2 4 // I2C Bus SDA (data)
#define D3 0 // 
#define D4 2 //  Blue LED 
#define D5 14 // SPI Bus SCK (clock)
#define D6 12 // SPI Bus MISO 
#define D7 13 // SPI Bus MOSI
#define D8 15 // SPI Bus SS (CS) 
#define D9 3 // RX0 (Serial console) 
#define D10 1 // TX0 (Serial console) 

const int powerPin = D3;
const int dataPin  = D5; // SER (pin 14)
const int latchPin = D6; // RCLK (pin 12)
const int clockPin = D7; // SRCLK (pin 11)
const int colonPin = D8;
const int encoderPinA = D9;
const int encoderPinB = D10;
const int encoderButtonPin = D0;


WiFiUDP ntpUDP;
NTPClient timeClient(ntpUDP, "pool.ntp.org", 0, 7200000); // Update time every two hours

// Set timezone rules.  Offsets set to zero, since they will be loaded from EEPROM
TimeChangeRule myDST = {"DST", Second, Sun, Mar, 2, 0};    
TimeChangeRule mySTD = {"STD", First, Sun, Nov, 2, 0};     
Timezone myTZ(myDST, mySTD);

#define OLED_RESET  LED_BUILTIN
#define SCREEN_WIDTH 128 // OLED display width, in pixels
#define SCREEN_HEIGHT 64 // OLED display height, in pixels
Adafruit_SSD1306 display(SCREEN_WIDTH, SCREEN_HEIGHT, &Wire, OLED_RESET);

const int debouncePeriod = 50;
const int longPressPeriod = 3000;  // Set longPressPeriod to 3 seconds.  Will manually turn on/off Nixies if button held for longer than 3 sec.
Switch encoderButton = Switch(encoderButtonPin, INPUT, LOW, debouncePeriod, longPressPeriod);
Ticker buttonTickler;
 
int encoderPos, encoderPosPrev;

enum Menu {
  TOP,
  SETTINGS1,
  SETTINGS2,
  SET_UTC_OFFSET,
  ENABLE_DST,
  SET_12_24,
  BLINK_COLON,
  CATHODE_PROTECT,
  AUTO_SHUTOFF,
  AUTO_SHUTOFF_ENABLE,
  AUTO_SHUTOFF_OFFTIME,
  AUTO_SHUTOFF_ONTIME,
  SHOW_ZERO,
  RESET_WIFI,
  SCREENSAVER_MENU,
  SCREENSAVER
} menu;

// EEPROM addresses
const int EEPROM_addr_UTC_offset  = 0; 
const int EEPROM_addr_DST         = 1;  
const int EEPROM_addr_12_24       = 2; 
const int EEPROM_addr_protect     = 3; 
const int EEPROM_addr_shutoff_en  = 4;
const int EEPROM_addr_shutoff_off = 5;
const int EEPROM_addr_shutoff_on  = 6;
const int EEPROM_addr_showzero    = 7;
const int EEPROM_addr_blink_colon = 8;
const int EEPROM_addr_screensaver = 9;

bool enableDST;         // Flag to enable DST
bool set12_24;          // Flag indicating 12 vs 24 hour time (0 = 12, 1 = 24);
bool showZero;          // Flag to indicate whether to show zero in the hour ten's place
bool enableBlink;       // Flag to indicate whether center colon should blink

uint8_t ssOption;       // Screen saver option (0=disabled, 1=scrolling image, 2=turn off OLED)

uint8_t interval_indx; // Cathode protection interval index
const int num_intervals = 6;
const int intervals[num_intervals] = {0, 15, 30, 60, 120, 240};  // Intervals in minutes, with 0 = off

bool enableAutoShutoff; // Flag to enable/disable nighttime shut off
int autoShutoffOfftime, autoShutoffOntime;  // On and off times from 0 to 95 in 15 minute intervals

time_t protectTimer = 0, menuTimer = 0;
bool nixieOn = true, manualOverride = false;
bool initProtectionTimer = false;  // Set true at the top of the hour to synchronize protection timer with clock

// Screensaver Bitmaps
#define INVADER_HEIGHT   16
#define INVADER_WIDTH    24
static const unsigned char PROGMEM invader1_bmp[] =
{ B00000110, B00000000, B01100000,
  B00000110, B00000000, B01100000,
  B01100001, B10000001, B10000110,
  B01100001, B10000001, B10000110,
  B01100111, B11111111, B11100110,
  B01100111, B11111111, B11100110,
  B01111110, B01111110, B01111110,
  B01111110, B01111110, B01111110,
  B01111111, B11111111, B11111110,
  B01111111, B11111111, B11111110,
  B00011111, B11111111, B11111000,
  B00011111, B11111111, B11111000,
  B00000110, B00000000, B01100000,
  B00000110, B00000000, B01100000,
  B00011000, B00000000, B00011000,
  B00011000, B00000000, B00011000};
        
static const unsigned char PROGMEM invader2_bmp[] =
{ B00000110, B00000000, B01100000,
  B00000110, B00000000, B01100000,
  B00000001, B10000001, B10000000,
  B00000001, B10000001, B10000000,
  B00000111, B11111111, B11100000,
  B00000111, B11111111, B11100000,
  B00011110, B01111110, B01111000,
  B00011110, B01111110, B01111000,
  B01111111, B11111111, B11111110,
  B01111111, B11111111, B11111110,
  B01100111, B11111111, B11100110,
  B01100111, B11111111, B11100110,
  B01100110, B00000000, B01100110,
  B01100110, B00000000, B01100110,
  B00000001, B11100111, B10000000,
  B00000001, B11100111, B10000000};
   
void setup() {
  pinMode(dataPin, OUTPUT);
  pinMode(latchPin, OUTPUT);
  pinMode(clockPin, OUTPUT); 
  pinMode(encoderPinA, INPUT_PULLUP);
  pinMode(encoderPinB, INPUT_PULLUP);
  pinMode(colonPin, OUTPUT);
  pinMode(powerPin, OUTPUT);

  digitalWrite(powerPin, true); // Set NCH6100HV power supply SHDN pin high (high voltage off)

  display.begin(SSD1306_SWITCHCAPVCC, 0x3C);  // OLED I2C Address, may need to change for different device,
                                              // Check with I2C_Scanner
  display.setTextSize(1);
  display.setTextColor(WHITE);
  display.clearDisplay();
  
  display.setCursor(0,0);
  display.println("Connecting...");
  display.println();
  display.println("Cycle Power after a");
  display.println("few minutes if no");
  display.print("connection.");
  display.display();

    // Setup WiFiManager
  WiFiManager MyWifiManager;
  MyWifiManager.setAPCallback(configModeCallback);
  MyWifiManager.autoConnect(AP_NAME,AP_PASSWORD); // Default password is PASSWORD, change as needed
  
  display.clearDisplay();
  display.setCursor(0,0);
  display.print("Wifi Connected");
  display.display();

  timeClient.begin();

  display.setCursor(0,28);
  display.println("Updating local time");
  display.display();
  while (!timeClient.update()) {
    delay(500);
    display.print(".");
    display.display();
  }

  EEPROM.begin(10);
  
  // Read UTC offset from EEPROM
  int utc_offset = (((int)EEPROM.read(EEPROM_addr_UTC_offset)+12) % 24) - 12;

  // Read Daylight Savings Time setting from EEPROM
  enableDST = EEPROM.read(EEPROM_addr_DST) != 0;

  mySTD.offset = utc_offset * 60;
  myDST.offset = mySTD.offset;
  if (enableDST) {
    myDST.offset += 60;
  }
  myTZ = Timezone(myDST, mySTD);

  // Read 12/24 hour setting from EEPROM
  set12_24 = EEPROM.read(EEPROM_addr_12_24) != 0;

  // Read cathode proection interval from EEPROM
  interval_indx = EEPROM.read(EEPROM_addr_protect);
  if (interval_indx >= num_intervals) interval_indx = 0;

  // Read auto shutoff settings
  enableAutoShutoff  = EEPROM.read(EEPROM_addr_shutoff_en) != 0;
  autoShutoffOfftime = (int)EEPROM.read(EEPROM_addr_shutoff_off);
  autoShutoffOntime  = (int)EEPROM.read(EEPROM_addr_shutoff_on);
  if (autoShutoffOfftime > 95) autoShutoffOfftime = 0;  // 96 15-minute intervals in day
  if (autoShutoffOntime > 95) autoShutoffOntime = 0;

  // Read show zero setting from EEPROM
  showZero = EEPROM.read(EEPROM_addr_showzero) != 0;

  // Read colon blink setting from EEPROM
  enableBlink = EEPROM.read(EEPROM_addr_blink_colon) != 0;

  // Read screensaver setting from EEPROM
  ssOption = EEPROM.read(EEPROM_addr_screensaver);
  if (ssOption > 2) ssOption = 0;
  
  menu = TOP;
  updateSelection();

  digitalWrite(powerPin, false); // Set NCH6100HV power supply SHDN pin low (high voltage on)
  timeClient.update();
  setTime(myTZ.toLocal(timeClient.getEpochTime()));
  displayTime();
  menuTimer = now();
  buttonTickler.attach_ms(20, buttonPoll); // Check button state every 20 msec
}

void loop() {  
  updateEncoderPos();

  // If button held for longer than 3 seconds, toggle Nixie tubes on/off
  if (encoderButton.longPress()){
    manualOverride = true;  // Overrides auto shutoff for this period
    nixieOn = !nixieOn;
    digitalWrite(powerPin, !nixieOn); // Toggle NCH6100HV power supply SHDN pin 
    menu = TOP;
    updateSelection(); 
  }

  if (encoderButton.pushed()) {
    menuTimer = now();  
    updateMenu();
   }

  timeClient.update();
  setTime(myTZ.toLocal(timeClient.getEpochTime()));

  // Cathode protection logic
  if (interval_indx > 0) {  // Cathode protection is enabled
    if ((menu != SET_UTC_OFFSET) && (menu != ENABLE_DST)) { // Changing UTC offset or DST setting can disrupt protection timer
      // At the first top of the hour, initialize cathode protection logic timer
      if (!initProtectionTimer && (minute() == 0)) {  
        protectTimer = 0;   // Ensures protection logic will be immediately triggered                                     
        initProtectionTimer = true;
      }
      if ((now() - protectTimer) >= 60 * intervals[interval_indx]) {
        protectTimer = now();
        // The current time can drift slightly relative to the protectTimer when NIST time is updated
        // Need to make a small adjustment to the timer to ensure it is triggered at the minute change
        protectTimer -= ((second()+30)%60 - 30);  
        if (nixieOn) cathodeProtect();
      }      
    }
  }
  
  static time_t prevTime = 0, refreshScreensaver = 0;
  if (now() != prevTime) { // Update time every second
    prevTime = now();
    evalShutoffTime();     // Check whether nixies should be turned off (Auto shutoff mode)
    displayTime();         // Update the time displayed on nixies and on OLED
    if (menu == SCREENSAVER) {
      if (now() - refreshScreensaver > 1800) { // OLED bitmap occasionally can get corrupted after a few hours
        updateSelection();                     // This will refresh screen saver bitmap every 30 minutes 
        refreshScreensaver = now();                 
      }
      else if ((ssOption == 1) && (mod(now(),3)==0)) { // Switch screensaver scroll direction every 3 seconds
        long r = random(2);  // Randomize switch between left and right
        if (r == 0) display.startscrolldiagright(0x00, 0x07);
        else display.startscrolldiagleft(0x00, 0x07);
      }
    }
  }
  // Reset screen to screensaver (if enabled) or top level if encoder inactive for more than 60 seconds
  // Note that UTC offset and DST setting changes can change now() by one hour
  // (3600 seconds), so modulus operator is needed
  if ((mod(now() - menuTimer, 3600) > 60) && (menu != SCREENSAVER)) { 
    if (ssOption > 0) {
      menu = SCREENSAVER;
      updateSelection();
      refreshScreensaver = now();      
    }
    else if (menu != TOP) {
      menu = TOP;
      updateSelection();     
    } 
  }
}

void cathodeProtect() {
  int hour12_24 = set12_24 ? (unsigned char)hour() : (unsigned char)hourFormat12();
  unsigned char hourBcd = decToBcd((unsigned char)hour12_24);
  unsigned char minBcd  = decToBcd((unsigned char)minute());
  unsigned char dh1 = (hourBcd >> 4), dh2 = (hourBcd & 15); 
  unsigned char dm1 = (minBcd >> 4),  dm2 = (minBcd & 15);

  // All four digits will increment up at 10 Hz.
  // At T=2 sec, individual digits will stop at 
  // the correct time every second starting from 
  // the right and ending on the left
  for (int i = 0; i <= 50; i++){
    if (i >= 20) dm2 = (minBcd & 15); 
    if (i >= 30) dm1 = (minBcd >> 4); 
    if (i >= 40) dh2 = (hourBcd & 15);
    if (i == 50) dh1 = (hourBcd >> 4);
    digitalWrite(latchPin, LOW);
    shiftOut(dataPin, clockPin, MSBFIRST, (dh1 << 4) | dh2);
    shiftOut(dataPin, clockPin, MSBFIRST, (dm1 << 4) | dm2);
    digitalWrite(latchPin, HIGH);
    incMod10(dh1); incMod10(dh2);
    incMod10(dm1); incMod10(dm2);
    delay(100);
  }
}

inline void incMod10(unsigned char &x) { x = (x + 1 == 10 ? 0: x + 1); };

void displayTime(){
   char tod[10], time_str[20], date_str[20];
   const char* am_pm[] = {"AM", "PM"};
   const char* month_names[] = {"Jan", "Feb", "March", "April", "May", "June", "July", "Aug", "Sept", "Oct", "Nov", "Dec"};
   int hour12_24 = set12_24 ? (unsigned char)hour() : (unsigned char)hourFormat12();
   unsigned char hourBcd = decToBcd((unsigned char)hour12_24);
   unsigned char minBcd  = decToBcd((unsigned char)minute());
   bool colonBlinkState = (bool)(second() % 2);

   if (!showZero && ((hourBcd >> 4) == 0)) { // If 10's digit is zero, we don't want to display a zero
    hourBcd |= (15 << 4); 
   }

   if (!nixieOn) {
    hourBcd = 255; 
    minBcd = 255;
    colonBlinkState = false;
   }
   else if (!enableBlink) {
    colonBlinkState = true;
   }
   
   // Write to shift register
   digitalWrite(latchPin, LOW);
   shiftOut(dataPin, clockPin, MSBFIRST, hourBcd);
   shiftOut(dataPin, clockPin, MSBFIRST, minBcd);
   digitalWrite(latchPin, HIGH);   

   digitalWrite(colonPin, colonBlinkState); // Blink colon pin
   
   if ((menu == TOP) || (menu == SET_UTC_OFFSET)) {
      formattedTime(tod, hour12_24, minute(), second());
      sprintf(time_str, "%s %s", tod, am_pm[isPM()]);
      sprintf(date_str, "%s %d, %d", month_names[month() - 1], day(), year());
      display.fillRect(20,28,120,8,BLACK);
      display.setCursor(20,28);
      display.print(time_str);
      if (enableDST) {
        if (myTZ.utcIsDST(timeClient.getEpochTime())) {
          display.print(" DST");
        }
        else {
          display.print(" STD");
        }
      }
      display.setCursor(20,36);
      display.print(date_str);
      display.display();
   }
}

unsigned char decToBcd(unsigned char val)
{
  return ( ((val/10)*16) + (val%10) );
}

#define colonDigit(digit) digit < 10 ? ":0" : ":"
void formattedTime(char *tod, int hours, int minutes, int seconds)
{
  sprintf(tod, "%d%s%d%s%d", hours, colonDigit(minutes), minutes, colonDigit(seconds), seconds);  // Hours, minutes, seconds
}

void evalShutoffTime() {  // Determine whether Nixie tubes should be turned off
  
  if (!enableAutoShutoff) return;
  
  int mn = 60*hour() + minute();
  int mn_on = 15*autoShutoffOntime;  
  int mn_off = 15*autoShutoffOfftime;

  static bool prevShutoffState = true;  
  if ( ((mn_off < mn_on) &&  (mn > mn_off) && (mn < mn_on)) ||  // Nixies should be off
        (mn_off > mn_on) && ((mn > mn_off) || (mn < mn_on))) { 
     if (!manualOverride){
      nixieOn = false;
      digitalWrite(powerPin, true); // Set NCH6100HV power supply SHDN pin high (high voltage off)
     }
     if (prevShutoffState == true) manualOverride = false; 
     prevShutoffState = false;
  }
  else {  // Nixies should be on
    if (!manualOverride){
      nixieOn = true;
      digitalWrite(powerPin, false); // Set NCH6100HV power supply SHDN pin low (high voltage on)
    }
    if (prevShutoffState == false) manualOverride = false; 
    prevShutoffState = true;
  }
    
}

void updateEncoderPos() {
    static int encoderA, encoderB, encoderA_prev;   

    encoderA = digitalRead(encoderPinA); 
    encoderB = digitalRead(encoderPinB);
 
    if((!encoderA) && (encoderA_prev)){ // A has gone from high to low 
      encoderPosPrev = encoderPos;
      encoderB ? encoderPos++ : encoderPos--;  
      menuTimer = now();
      if (menu != TOP) {
        updateSelection();
      }    
    }
    encoderA_prev = encoderA;     
}

#ifdef CLOCK_COLON
  const int n_set1 = 6;  // 6 menu items on Settings 1
#else
  const int n_set1 = 5;  // Otherwise, only 5 items
#endif

void updateMenu() {  // Called whenever button is pushed

  switch (menu) {
    case TOP:
      menu = SETTINGS1;
      break;
      
    case SCREENSAVER:
      display.stopscroll();
      menu = SETTINGS1;
      break;
      
    case SETTINGS1:
      switch (mod(encoderPos,n_set1)) {
        case 0: // Timezone Offset
          menu = SET_UTC_OFFSET;
          break;
        case 1: // Enable DST
          menu = ENABLE_DST;
          break;
        case 2: // 12/24 Hours
          menu = SET_12_24;
          break;
          
#ifdef CLOCK_COLON
        case 3: // Blink Colon
          menu = BLINK_COLON;
          break;  
        case 4: // More Options
          menu = SETTINGS2;
          break;
        case 5: // Return
          menu = TOP;
          break;
#else
        case 3: // More Options
          menu = SETTINGS2;
          break;
        case 4: // Return
          menu = TOP;
          break;
#endif
      }
      break;
    case SETTINGS2:
      switch (mod(encoderPos,6)) {
        case 0: // Cathod Protection
          menu = CATHODE_PROTECT;
          break;
        case 1: // Auto Shut off
          menu = AUTO_SHUTOFF;
          break;
        case 2: // Enable Screensaver
          menu = SCREENSAVER_MENU;
          break;
        case 3: // Show Zero
          menu = SHOW_ZERO;
          break;
        case 4: // Reset Wifi
          menu = RESET_WIFI;
          break;
        case 5: // Return
          menu = SETTINGS1;
          break;
      }
      break;
      
    case RESET_WIFI:
      if (mod(encoderPos, 2) == 1){  // Selection = YES
        resetWiFi();
        menu = TOP; 
      }
      else {  // Selection = NO
        menu = SETTINGS1;
      }
      break;
      
    case SET_UTC_OFFSET:
      EEPROM.write(EEPROM_addr_UTC_offset, (unsigned char)(mod(mySTD.offset/60,24))); 
      EEPROM.commit();
      initProtectionTimer = false;
      menu = SETTINGS1;
      break;
      
    case ENABLE_DST:
      EEPROM.write(EEPROM_addr_DST, (unsigned char)enableDST);
      EEPROM.commit();
      initProtectionTimer = false;
      menu = SETTINGS1; 
      break;
      
    case SET_12_24:
      EEPROM.write(EEPROM_addr_12_24, (unsigned char)set12_24);
      EEPROM.commit();
      menu = SETTINGS1;
      break; 

    case BLINK_COLON:
      EEPROM.write(EEPROM_addr_blink_colon, (unsigned char)enableBlink);
      EEPROM.commit();
      menu = SETTINGS1;
      break;
     
    case CATHODE_PROTECT: 
      EEPROM.write(EEPROM_addr_protect, interval_indx);
      EEPROM.commit();
      initProtectionTimer = false;
      protectTimer = 0;
      menu = SETTINGS2;
      break;
      
    case AUTO_SHUTOFF: 
      switch (mod(encoderPos,4)) {
        case 0: 
          menu = AUTO_SHUTOFF_ENABLE;
          break;
        case 1: 
          menu = AUTO_SHUTOFF_OFFTIME;
          break;
        case 2: 
          menu = AUTO_SHUTOFF_ONTIME;
          break;
        case 3: 
          menu = SETTINGS2;
          break;
      }
      break;
      
    case AUTO_SHUTOFF_ENABLE:
      EEPROM.write(EEPROM_addr_shutoff_en, (unsigned char)enableAutoShutoff);
      EEPROM.commit();
      menu = AUTO_SHUTOFF;
      break;
      
    case AUTO_SHUTOFF_OFFTIME:  
      EEPROM.write(EEPROM_addr_shutoff_off, (unsigned char)autoShutoffOfftime);
      EEPROM.commit();
      menu = AUTO_SHUTOFF;
      break;
      
    case AUTO_SHUTOFF_ONTIME: 
      EEPROM.write(EEPROM_addr_shutoff_on, (unsigned char)autoShutoffOntime);
      EEPROM.commit();
      menu = AUTO_SHUTOFF;
      break;
      
    case SCREENSAVER_MENU: 
      {
        int opt = mod(encoderPos,4);
        if (opt < 3) {
          ssOption = (uint8_t) opt;
          EEPROM.write(EEPROM_addr_screensaver, (unsigned char)ssOption);
          EEPROM.commit();
        }
        else menu = SETTINGS2;  // Return
      }
      break;
      
    case SHOW_ZERO: 
      EEPROM.write(EEPROM_addr_showzero, (unsigned char)showZero);
      EEPROM.commit();
      menu = SETTINGS2;
      break;
  }
  encoderPos = 0;  // Reset encoder position
  encoderPosPrev = 0;
  updateSelection(); // Refresh screen
}
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

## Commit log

2016-12-02 Check in source code and related files.
    [NixieClockCase.skp, NixieClockCaseBase.stl, NixieClockCaseCover.stl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]
2016-12-02 Make Switch an Arduino library and remove from repository
2018-06-03 Updated cathode protection logic. Added schematic and board pdfs.
2018-06-04 Fix bug when changing UTC and DST settings
    [ESP_NIXIE.ino]
2018-06-09 Fixed WiFi reset issue
    [ESP_NIXIE.ino]
2019-01-05 Added code to blink optional colon circuit
2019-01-13 Add colon separator PCB and case
    [NixieBaseWithColon.stl, NixieClockCase.skp, NixieClockCaseBase.stl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]
2019-12-24 Added NCH6100HV SHDN pin support.
2019-12-29 Pull-up resistor update

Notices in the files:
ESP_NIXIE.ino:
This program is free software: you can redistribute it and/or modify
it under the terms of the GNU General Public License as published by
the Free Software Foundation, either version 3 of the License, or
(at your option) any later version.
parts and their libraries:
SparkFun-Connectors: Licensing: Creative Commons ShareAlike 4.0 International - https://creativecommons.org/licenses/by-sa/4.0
